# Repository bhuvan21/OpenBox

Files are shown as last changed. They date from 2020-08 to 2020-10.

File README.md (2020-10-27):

# OpenBox  
An open source, arduino based fencing scoring box. Created with a low budget in mind (costs ~£50 to build), but maximal portability and functionality.  

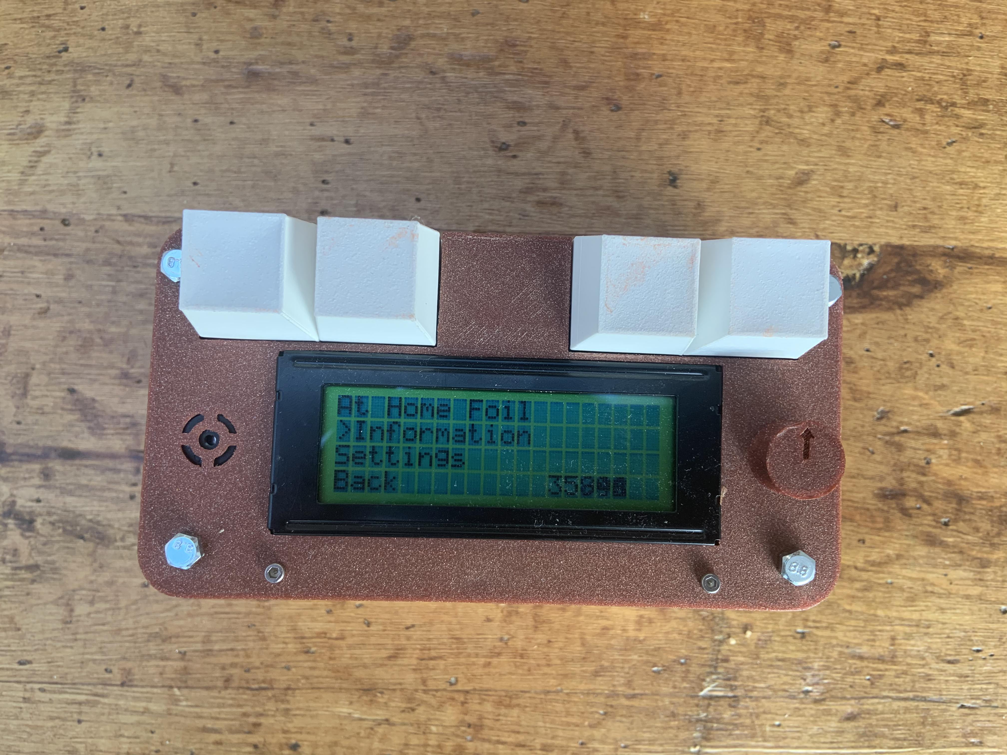
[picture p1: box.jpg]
Picture of the box
  

The hardware of this fencing box has been meticulously planned, designed, and put together.  
The software for the box is not yet finished, with only the at-home foil practice, as well as some settings being done.  

## Hardware  
All information on the physical build is contain in BUILD.md, within the build subdirectory.

## Software  
There are quite a few test scripts present in /tests/ which can be used for ensuring that all components connected to the microcontroller are functioning correctly.  
The main box script resides in /main/  

## Roadmap
Though still in the development stage, I think this has the potential to become a viable product. I hope to refine my design further and start deploying them in clubs, schools and tournaments.

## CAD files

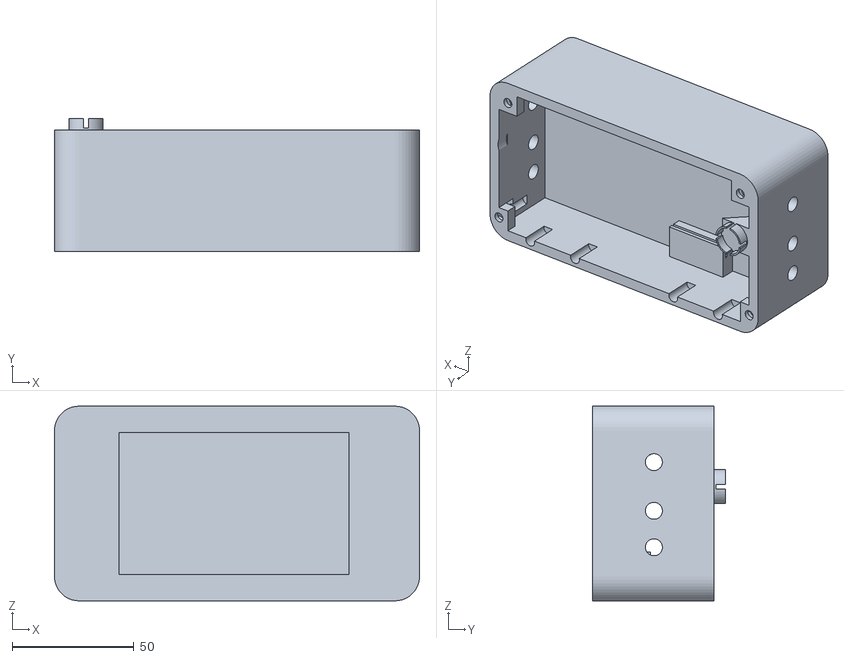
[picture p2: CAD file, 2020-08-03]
build/bottombox.stl
150.0 x 54.8 x 80.0

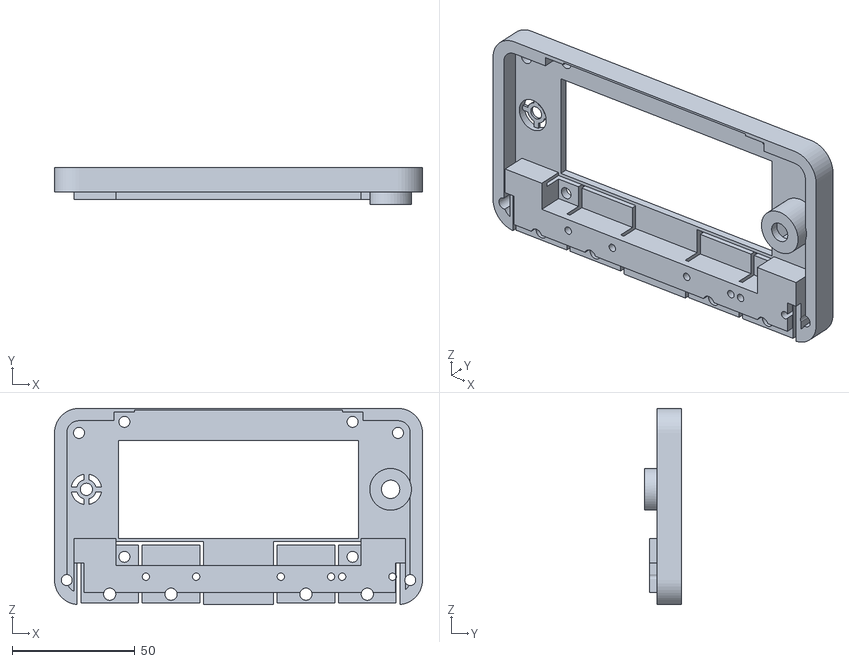
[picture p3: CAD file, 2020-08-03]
build/topbox.stl
150.0 x 15.0 x 80.0

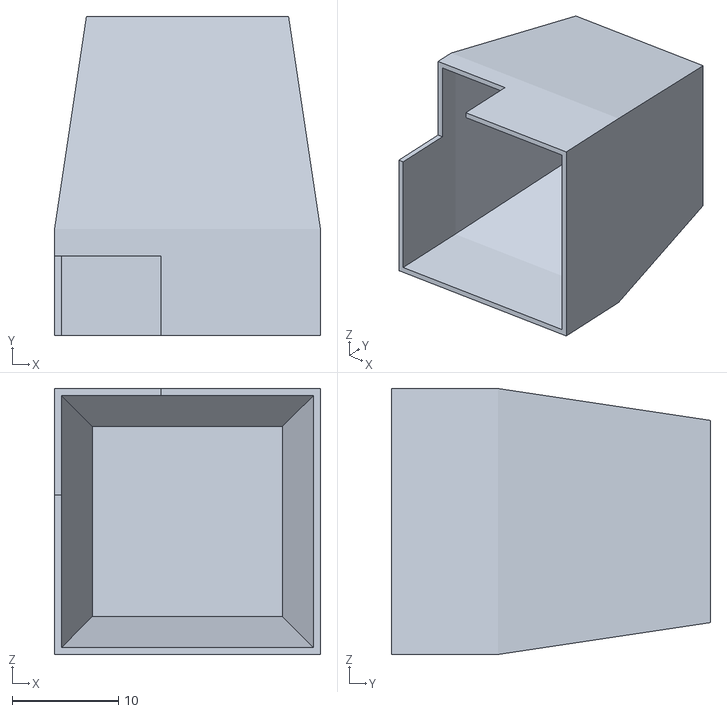
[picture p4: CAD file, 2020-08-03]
build/halfdiffuser.stl
25.0 x 30.0 x 25.0

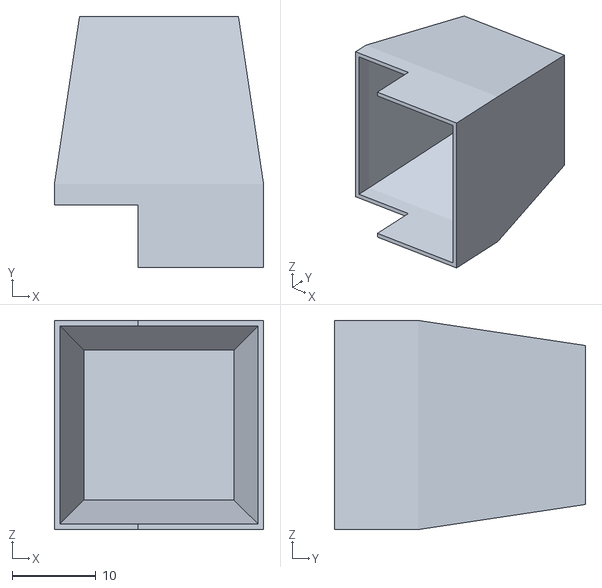
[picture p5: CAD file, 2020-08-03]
build/quartdiffuser.stl
25.0 x 30.0 x 25.0

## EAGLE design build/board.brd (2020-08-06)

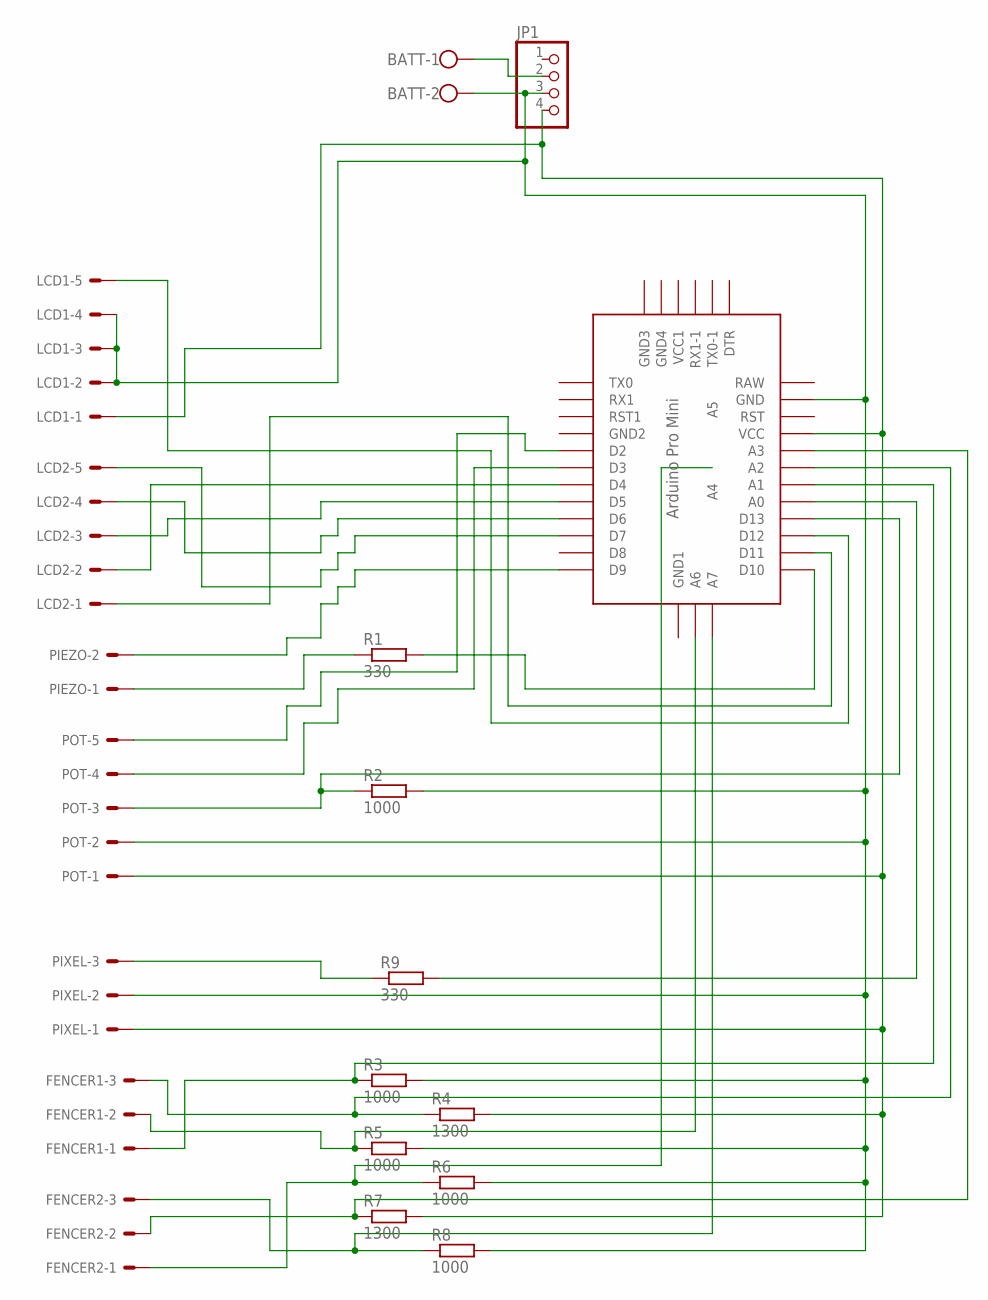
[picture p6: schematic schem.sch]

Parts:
BATT: W237-102
FENCER1, FENCER2: 22-27-2031-03; 6410-03
JP1: PINHD-1X4; 1X04
LCD1, LCD2: 22-27-2051-05; 6410-05
PIEZO: 22-27-2021-02; 6410-02
PIXEL: 22-27-2031-03; 6410-03
POT: 22-27-2051-05; 6410-05
R1: 330; 0204/7
R2, R3, R5, R6, R8: 1000; 0204/7
R4, R7: 1300; 0204/7
R9: 330; 0207/10
U$1: ABK-PRO-MINI

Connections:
unnamed: JP1.4, LCD1.1, PIXEL.1, POT.1, R4.2, R7.2, U$1.VCC
unnamed: BATT.2, JP1.3, LCD1.2, LCD1.3, LCD1.4, PIXEL.2, POT.2, R2.2, R3.2, R5.2, R6.2, R8.2, U$1.GND
unnamed: BATT.1, JP1.2
unnamed: LCD2.4, U$1.D6
unnamed: LCD2.1, U$1.D11
unnamed: LCD1.5, U$1.D12
unnamed: LCD2.2, U$1.D4
unnamed: LCD2.3, U$1.D5
unnamed: LCD2.5, U$1.D7
unnamed: PIEZO.2, U$1.D9
unnamed: PIEZO.1, R1.1
unnamed: R1.2, U$1.D10
unnamed: POT.5, U$1.D2
unnamed: POT.4, U$1.D3
unnamed: FENCER1.1, R3.1, U$1.A1
unnamed: POT.3, R2.1, U$1.D13
unnamed: R9.2, U$1.A0
unnamed: FENCER1.3, R4.1, U$1.A2
unnamed: FENCER1.2, R5.1, U$1.A6
unnamed: FENCER2.1, R6.1, U$1.A4
unnamed: FENCER2.3, R8.1, U$1.A7
unnamed: PIXEL.3, R9.1
unnamed: FENCER2.2, R7.1, U$1.A3

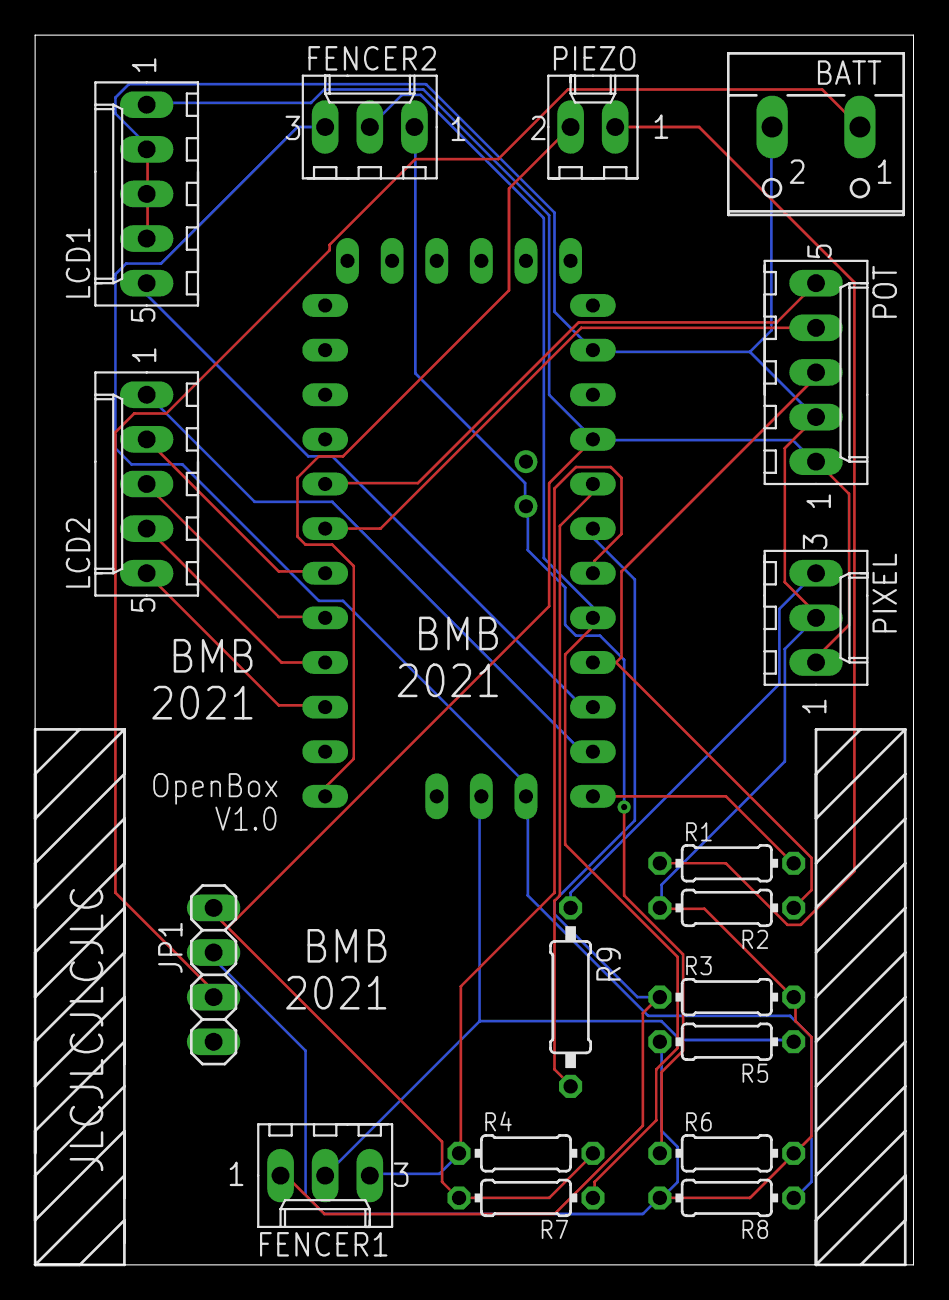
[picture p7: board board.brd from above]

Board: 2 copper layers, 50.0 x 70.0 mm, 19 parts (0 on the bottom side), 23 nets.

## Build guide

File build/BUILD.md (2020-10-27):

# OpenBox Build

This is actually a relatively simple build! This cost me about £50 to produce, though there are slightly higher costs if these boxes are made not by me (there are one time costs for the first box, like soldering equipment, programming cable etc.)

Though not present here yet, I plan to write a full build guide so that others can produce this box for themselves! I'm holding off on doing that until I'm fully satisfied with the featureset of the box's software and the sourcing of the components.

## Files in the folder
topbox.stl and bottombox.stl are the two stl files which must be 3D printed for the box's housing. I printed these in PLA with standard supports, at a layer height of 0.2mm.  
halfdiffuser.stl and quarterdiffuser.stl are two stl files for the light diffuser caps present on the top of the box. These must be printed in white PLA, two of each are needed.  
schem.sch and board.brd are the Eagle PCB files which make up the custom PCB control board used for this project.  

## Hardware Overview  
The basic overview of this board is as follows. The main control board starts with the custom PCB present in this folder. Once molex headers, regular pin headers and a screw terminal are soldered in, an Arduino Mini Pro and S7V8F5 5V Regulator can be inserted into the board, through the pin headers soldered on. Some resistors need to be soldered on too.  
  
A 6xAA battery holder attached to the screw terminal which is VIN for the board. This line is regulated by the 5V regulator, and the output of this powers the Arduino.  

The external components (rotary encoder, LCD, Neopixels, Piezo, Banan Plugs) must be soldered to crimped molex wires, which in turn form molex connectors to connect to the main board. The pins for this are detailed in the board schematic file.  

The external components are held in place in the 3D printed chassis via nuts and bolts, or mechanical solutions (board slides into rails, light caps are a friction fit).  

That's about it! There's not much complicated wiring here as everything happens on the control board.

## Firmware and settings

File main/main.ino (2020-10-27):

#include <LiquidCrystal.h>
#include <toneAC.h>
#include <Adafruit_NeoPixel.h>
#ifdef __AVR__
 #include <avr/power.h>
#endif
#include <avr/sleep.h>
#include <Encoder.h>
#define EI_NOTEXTERNAL
#include <EnableInterrupt.h>

#define LED_PIN    A3
#define LED_COUNT 4
Adafruit_NeoPixel strip(LED_COUNT, LED_PIN, NEO_GRB + NEO_KHZ800);

const int rs = 12, en = 11, d4 = 4, d5 = 5, d6 = 6, d7 = 7;
LiquidCrystal lcd(rs, en, d4, d5, d6, d7);

#define BUTTON 13

int timeSinceInteraction = 9999;
long lastInteraction = 0;

int rotarySelection = 0;
int baseLine = 0;
Encoder myEnc(3, 2);

int menuIndex = 0;


bool sleeping = false;

int navigation[6][10] = {{1,2,4,0,0,0,0,0,0,0}, {0,3,0,0,0,0,0,0,0}, {0,0,0,0,0,0,0,0,0,0}, {0,0,0,0,0,0,0,0,0,0}, {5,0,0,0,0,0,0,0,0,0}, {0,0,0,0,0,0,0,0,0,0}};

volatile bool flag = false;

long pressTime;

long lightsOff;


bool foilHome2Flag = false;
volatile bool hitFlags1[] = {false};

volatile bool hitFlagChange1 = false;
volatile bool hitFlagRise1 = false;
volatile bool hitFlagFall1 = false;


volatile bool skipMain = false;
volatile bool interRead;

volatile long hitGo;

bool buttonPressed = false;

uint32_t selectedColor2 = strip.Color(0, 0, 255);

void setup() {
  Serial.begin(2000000);
  Serial.println("Started.");

  
  strip.begin();
  strip.show();
  strip.setBrightness(100);
  strip.setPixelColor(0, strip.Color(0, 0, 0));
  strip.setPixelColor(1, strip.Color(0, 0, 0));
  strip.setPixelColor(2, strip.Color(0, 0, 0));
  strip.setPixelColor(3, strip.Color(0, 0, 0));


  strip.show();
  
  lastInteraction = millis();
  lcd.begin(20, 4);
  lcd.display();


  

  pinMode(BUTTON, INPUT);
  updateScreen();

  pinMode(A0, INPUT);
  enableInterrupt(A0, f3, RISING);
  
  enableInterrupt(BUTTON, middlePressed, RISING);
}



void loop() {
  long startWait = millis();

  // WAIT 50ms but break out if an interrupt happened and something needs to be done
  while (millis()-startWait < 50) {
    if (hitFlagChange1) {
      break;
    }
  }

  // DETERMINE RISE OR FALL FOR F2
  if (hitFlagChange1) {
    Serial.print("Rising:");
    
    while (digitalRead(A0) == HIGH) {
      if (millis() - hitGo >= 13) {
        setLightsNoStop(true, false, false, false);
        //toneAC(2000);

      }
    }
    int pressed = millis() - hitGo;
    if (pressed >= 13) {
      Serial.print("Sucessful Hit of length");
      Serial.println(pressed);
      setLights(true, false, false, false);
      toneAC(2000);
    }
    else {
      Serial.print("Fail Hit of length");
      Serial.println(pressed);
      lightsOff = millis();
    }

    hitFlagChange1 = false;


    
  }





  if (millis() >= lightsOff) {
    //Serial.println("Lights and piezo off.");
    strip.setPixelColor(0, strip.Color(0, 0, 0));
    strip.setPixelColor(1, strip.Color(0, 0, 0));
    strip.setPixelColor(2, strip.Color(0, 0, 0));
    strip.setPixelColor(3, strip.Color(0, 0, 0));
    toneAC(0);
    strip.show();
    
  }

  if (!skipMain) {

    lcd.setCursor(13, 3);
    lcd.print(millis());
  
    
    
  
    
    timeSinceInteraction = millis() - lastInteraction;
    if (timeSinceInteraction > 10000){
      
      lcd.clear();
      sleeping = true;
      sleep_enable();//Enabling sleep mode
      set_sleep_mode(SLEEP_MODE_PWR_DOWN);//Setting the sleep mode, in our case full sleep
      sleep_cpu();//activating sleep mode
    }
    else {
      long newPos = myEnc.read();
  
        if (newPos != rotarySelection) {
          if (abs(rotarySelection*20 - newPos) >= 20.0) {
            lastInteraction = millis();
            rotarySelection = floor(newPos/20.0);
            updateScreen();
          }
          
        }
      
    }
    
  }
  
  
  

}

void updateScreen() {
  lcd.clear();
  String options[10] = {"Back", "Back", "Back", "Back", "Back", "Back", "Back", "Back", "Back", "Back"};
  if (menuIndex == 0) {
    options[0] = "At Home Foil";
    options[1] = "Information";
    options[2] = "Settings";
  }
  else if (menuIndex == 1) {
    options[0] = "Flick Testing";
    options[1] = "Regular Testing";
  }
  else if (menuIndex == 2) {
    lcd.clear();
    lcd.setCursor(0, 0);
    lcd.print("Info Page");
    return;
  }
  else if (menuIndex == 3) {
    lcd.clear();
    lcd.setCursor(0, 0);
    lcd.print("Regular Testing Mode");
    lcd.setCursor(0, 3);
    lcd.print("ON!");
    skipMain = true;
    return;
  }
  else if (menuIndex == 4) {
    options[0] = "Light #1 Colors";
  }
  else if (menuIndex == 5) {
    options[0] = "Red";
    options[1] = "Blue";
    options[2] = "Pink";
  }

  int optionCount = 0;
  int startIndex = 0;
  int endIndex = 0;

  
  
  for (int i = 0; i < 10; i++) {
    if (options[i] == "Back") {
      optionCount = i+1;
      break;
    }
  }

  if ((rotarySelection - baseLine) > optionCount-1) {
    baseLine = (rotarySelection+1) - optionCount;
  }

  if ((rotarySelection - baseLine) < 0) {
    baseLine = rotarySelection;
  }

  if (optionCount <=4) {
    endIndex = optionCount-1;
  }
  else {
    int selection = (rotarySelection - baseLine);
    if (selection <=4) {
      endIndex = 4;
    }
    else {
      startIndex = selection;
      endIndex = startIndex+4;
    }
  }

  for (int i = startIndex; i < endIndex+1;i++) {
    lcd.setCursor(0, i-startIndex);
    if (i == (rotarySelection - baseLine)) {
      lcd.print(">");
    }
    lcd.print(options[i]);
  }
  lcd.setCursor(4, 20);
  

}

void menuSelect() {
  skipMain = false;
  int basics[] = {2, 3};
  bool flag = false;
  for (int i = 0; i<2; i++) {
    if (basics[i] == menuIndex) {
      flag = true;
    }
  }

  if (menuIndex == 5) {
    if (rotarySelection-baseLine == 0) {
      selectedColor2 = strip.Color(255, 0, 0);
    }
    else if (rotarySelection-baseLine == 1) {
      selectedColor2 = strip.Color(0, 0, 255);
    }
    else if (rotarySelection-baseLine == 2) {
      selectedColor2 = strip.Color(255, 108, 180);
    }
  }
  
  if (flag) {
    menuIndex = 0;
  }
  else {
    menuIndex = navigation[menuIndex][rotarySelection-baseLine];
    baseLine = rotarySelection;
  }
  updateScreen();
}



void setLights(bool a, bool b, bool c, bool d) {
  if (a) {
    strip.setPixelColor(0,selectedColor2);
  }
  
  if (b) {
    strip.setPixelColor(0, strip.Color(255, 255, 255));
  }

  if (c) {
    strip.setPixelColor(0, strip.Color(255, 255, 255));
  }

  if (d) {
    strip.setPixelColor(0, strip.Color(0, 0, 255));
  }
  strip.show();

  lightsOff = millis() + 2000;
}

void setLightsNoStop(bool a, bool b, bool c, bool d) {
  if (a) {
    strip.setPixelColor(0, selectedColor2);
  }
  
  if (b) {
    strip.setPixelColor(0, strip.Color(255, 255, 255));
  }

  if (c) {
    strip.setPixelColor(0, strip.Color(255, 255, 255));
  }

  if (d) {
    strip.setPixelColor(0, strip.Color(0, 0, 255));
  }
  strip.show();
  lightsOff = millis() + 999999;
}



void middlePressed() {
  if (buttonPressed) {
    buttonPressed = false;
  }
  else {
    buttonPressed = true;
     if (sleeping) {
    
      //bool buttonState = digitalRead(BUTTON);
      lastInteraction = millis();
      sleeping = false;
      updateScreen();
      sleep_disable();//Disable sleep mode
    }
    else {
      menuSelect();
    }
  }

}

void f3() {
  hitGo = millis();
  hitFlagChange1 = true;
  lastInteraction = millis();
  sleeping = false;
  sleep_disable();
}

void f2() {
  int t = PINC;
  int a = t & B00000001;
  if (a == 0) {
    interRead = false;
  }
  else {
    interRead = true;
  }
    if (menuIndex == 3) {
      hitFlagChange1 = true;
      
    lastInteraction = millis();
    sleeping = false;
    sleep_disable();
    }
}

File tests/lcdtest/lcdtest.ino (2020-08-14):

/*
  LiquidCrystal Library - Hello World

 Demonstrates the use a 16x2 LCD display.  The LiquidCrystal
 library works with all LCD displays that are compatible with the
 Hitachi HD44780 driver. There are many of them out there, and you
 can usually tell them by the 16-pin interface.

 This sketch prints "Hello World!" to the LCD
 and shows the time.

  The circuit:
 * LCD RS pin to digital pin 12
 * LCD Enable pin to digital pin 11
 * LCD D4 pin to digital pin 5
 * LCD D5 pin to digital pin 4
 * LCD D6 pin to digital pin 3
 * LCD D7 pin to digital pin 2
 * LCD R/W pin to ground
 * LCD VSS pin to ground
 * LCD VCC pin to 5V
 * 10K resistor:
 * ends to +5V and ground
 * wiper to LCD VO pin (pin 3)

 Library originally added 18 Apr 2008
 by David A. Mellis
 library modified 5 Jul 2009
 by Limor Fried (http://www.ladyada.net)
 example added 9 Jul 2009
 by Tom Igoe
 modified 22 Nov 2010
 by Tom Igoe

 This example code is in the public domain.

 http://www.arduino.cc/en/Tutorial/LiquidCrystal
 */

// include the library code:
#include <LiquidCrystal.h>

// initialize the library with the numbers of the interface pins
LiquidCrystal lcd(12, 11, 4, 5, 6, 7);

void setup() {
  // set up the LCD's number of columns and rows:
  lcd.begin(20, 4);
  // Print a message to the LCD.
  lcd.clear();
  lcd.print("hello, world!");
}

void loop() {
  // set the cursor to column 0, line 1
  // (note: line 1 is the second row, since counting begins with 0):
  lcd.setCursor(0, 1);
  // print the number of seconds since reset:
  lcd.print(millis() / 1000);
}

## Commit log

2020-08-03 Initial Commit, test sketches, pcb, stls
    [board.brd, bottombox.stl, halfdiffuser.stl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]
2020-08-06 New Molex version of PCB
    [board.brd, schem.sch]
2020-08-14 New interrupts
